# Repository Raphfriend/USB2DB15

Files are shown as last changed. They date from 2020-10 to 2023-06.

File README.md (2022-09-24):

# USB2DB15 - Supergun Adapter  


A simple Atmega328P based USB to DB15 adapter designed for use with a Supergun or Neo-Geo system.

<p align="center">
  
 <br>
  <b>USB2DB15 with a Sega Astro City Mini Arcade Stick</b><br>
<br>
	</p>  	

### 1. Features:

- USB input to support most modern HID compatible controllers
- 1ms polling, meaning a low latency and fast response from the USB2DB15
- Open Source firmware, so everyone on the community can collaborate
- DB15 pinout standard, ready for Neo Geo, Minigun, and HAS Superguns
- 4 customizable and storable mapping configurations
- 10 customizable and storable controller profiles
- Status LED
- Protection circuit for your beloved controllers

### 2. Technical information:

The USB2DB15 adapter is an Open Sourced device based on an AVR microcontroller. It adapts a USB controller for use with a Jamma PCB via a Supergun or Neo-Geo hardware with controller ports. Presently, a variety of common controllers are supported; such as ones that follow the PS3/PS4 DualShock, PS5 DualSense and Xbox 360/One protocols. Due to the diversity of controllers available and differing standards there may be some controllers that will not work with the USB2DB15 or may not work as intended. Please be patient during these early stages. Feel free to contact the developers with additional information and requests for help with your USB2DB15 adapter via our communication channels (GitHub, Discord, Arcade-Projects forum).

We are using a modified USB Host Shield 2.0 library for controller IDs that aren't natively supported.

In regards to hardware there are currently two options:

- A Custom PCB that accommodates and integrates an Arduino Pro Mini, USB Shield Mini and other relevant hardware.
- USB2DB15 2.0 Ver, a pre-built, single PCB that incorporates all the required hardware in a standalone form.
- USB2DB15 CS Ver, same as 2.0 Ver, but with a focus on PCB consolization. In place of the DB15 controller connector, this board has screw terminals and a 20 pin header which is compatible with a 20-pin Brook Fighting Board Cable.

Alternatively you can simply use a breadboard to connect it all together. 

If you are building the open source version for yourself, a basic understanding of Arduino and its programming environment is required. Visit [arduino.cc](https://arduino.cc) to help you get started.

<p align="center">
  
 <br>
  <b>USB2DB15 pinout standard</b><br>
<br>

### 3. Open Source Required Hardware:

* The USB2DB15 uses an Atmega328P AVR. Any Arduino that utilizes this microcontroller such as the Mini Pro, Nano, and Uno are suitable. The Custom PCB accommodates an Arduino Mini Pro and USB Host Shield Mini.
* USB Host Shield Mini if using an Arduino Pro Mini / Nano. Full sized USB Host Shield for Uno.
* An FTDI programmer is required for the Arduino Pro Mini. This is not required if using an Arduino Nano or Uno.
* USB2DB15 Custom PCB or a breadboard to complete all the connections between the AVR and USB Host Shield.
* DB15 female connector.

<p align="center">
  
 <br>
  <b>Arduino Pro Mini and Usb Host Shield Mini</b><br>
<br>
	</p>  	

If utilizing the Custom PCB in conjunction with an Arduino Pro Mini and Mini USB Shield, a BOM is available from the repositories section within the PCB folder. 

##### Jumper settings:

- SJ1: Bridge this jumper ONLY to disable 5V protection.
- SJ2: Bridge this jumper ONLY to enable 5V protection.
- JP2: 5V solder point (see information below regarding USB VBUS).

Due to variances of Mini Pro PCB's, A4 and A5 may be in different locations. Please pay attention to this.

<p align="center">

 <br>
  <b>Custom PCB 1.2 for Arduino Pro Mini</b><br>
</p>

### 4. Installation:

Download the  <a href="https://github.com/Raphfriend/USB_Host_Shield_2.0">USB Host Shield 2.0 library</a>  and install it to the Arduino IDE. Open the INO file (RFUSB_to_DB15.ino) and program it to your AVR.  

If you have a USB Host Shield Mini, you will need to CUT the trace after the 2K2 resistor near the USB VBUS pin. Solder a wire from JP2 of the CUSTOM PCB to the through-hole VIA labeled '5V' as depicted in the picture below.

<p align="center">
  
</p>

This enables devices that require +5V power to function correctly, as by default the USB Host Shield Mini only supplies 3.3V to the VBUS pin of the USB connector.

The remainder is plug and play. 

If you are not using a prefabricated PCB, please view the schematic for wiring information.

#### 4.1. Arduino Pro Mini + USB Shield Mini:
[See FLASHING.md for instructions.](FLASHING.md)

#### 4.2. Arduino Uno + USB Host Shield:

1. Install Arduino IDE.
2. Mount the USB Host Shield to the Arduino Uno correctly.
3. Connect the Arduino Uno to your PC via its USB B cable. 
4. In the Arduino IDE navigate to "Tools" -> "Board" -> "Arduino AVR Boards" and select "Arduino Uno".
5. In the Arduino IDE navigate to "Tools" -> "Port" and choose the Arduino Device. 
6. In the Arduino IDE navigate to "Tools" -> "Programmer" and select "AVRISP MKII".
7. Obtain the library path (Arduino IDE -> File -> Preference-> Settings->Sketchbook location) and drop the required library "USB_Host_Shield_20" to the library directory.
8. Obtain the INO firmware (RFUSB_to_DB15.ino).
9. Open the INO file with the Arduino IDE (with the Arduino Uno connected to your PC) and select Sketch -> Upload.
10. Wait for the sketch to be uploaded as indicated in the console window at the bottom of the Arduino IDE software.

### 5. Supported Controllers:

[See Compatibility.md for a detailed list of supported controllers.](COMPATIBILITY.md)

### 6. Software Usage
#### 6.1 Controller Profiles
The Adapter can store profiles for up to 10 unique controller models*. Controllers of the same make and model will share the profiles.
Each controller has 4 profiles associated with it. Should you plug in an 11th controller the system will replace the oldest controller you have set up.
Next oldest for the 12th and so on. This may cause you to have to set up older controllers again if you resume using them.

These can be accessed by pressing SELECT(COIN) + one of the four directions.
Thus if you wanted the first profile you would press SELECT + UP, the Second SELECT + RIGHT, and so on.
The adapter will remember what profile you were using and automatically switch to it when you use the controller again.

To change the key bindings of a profile. First change to the profile you want to setup.
While holding SELECT for at least 3 seconds, press buttons 1 - 6 in order. Then release SELECT to lock in the binding.
Finally release SELECT to lock in the binding.

*XBox One controllers appear to the system as the same make and model and thus use the same profiles even if they are different controllers.

### Shell

[AvramCE](https://twitter.com/avramce) has created a [3D printed case](https://www.thingiverse.com/thing:5170415) that you can print for your USB2DB15.

### How it looks in real life?

When you put all the parts together, USB2DB15 should look like this.
<p align="center">
  
	 <br>
  <b>Setup and photo by <a href="https://twitter.com/Focux11">@Focux</a> </b>
	</p>  	
<p align="center">
  
	 <br>
    <b>Setup and photo by <a href="https://twitter.com/_atrac17">@_atrac17</a> </b>
	</p>  	

### Support this project

If you have found USB2DB15 useful, please consider funding it and making a donation so that we may continue our work by obtaining additional controllers, equipment, and everything else required to keep this project alive and growing.



### Is this product available to buy? YES!

We sell the USB2DB15 directly. You will receive a premium edition that is slightly different from the open-source version but has the same features.
You can choose from a variety of shell color options, and you will get detailed instructions following your purchase.
There are two versions: the standard DB15 and the CS Ver., which is targeted towards Jamma PCB consolizations. 

<a href="https://ko-fi.com/s/b6c3d01043">Access our shop by clicking here or on the images below. </a>

<p align="center">
<a href="https://ko-fi.com/s/b6c3d01043">
  
</p>

<p align="center">
<a href="https://ko-fi.com/s/b6c3d01043">
  
</p>

<p align="center">
<a href="https://ko-fi.com/s/b6c3d01043">
  
</p>

<p align="center">
<a href="https://ko-fi.com/s/b6c3d01043">
  
</p>

### Where can I get more help, if I need it?

Via Arcade-Projects forum or RF Projects Discord server.

<p align="center">
<a href="https://www.arcade-projects.com/forums/index.php?thread/14205-open-source-usb-to-db15-for-supergun-adapter/">
  
</p>

<p align="center">
<a href="https://discord.gg/XKCjtpH">
  
</p>

### LEGAL

USB2DB15 or any of its maintainers are in no way associated with or endorsed by Nintendo, Sony, SNK, Microsoft, 8BitDo, Sega, Brook, Mad Catz, Nacon, Honcam, DaemonBite, Buffalo, Qanba, Razer, Retrobit, Toodles, Hori or any other company not implicitly indicated. All other brands or product names are the property of their respective holders.

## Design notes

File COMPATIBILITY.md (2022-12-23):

## Known Compatible Controllers by Manufacturer
This is a list of tested controllers. Please reach out to our Discord server if you have a controller not listed here and wish to be a tester.  You will need to test each beta version of the software for regressions

### 8BitDo
- M30 Bluetooth Controller
	- Via wired connection
	- Place controller into D-INPUT mode by holding B + START upon powering ON controller
	- Press SELECT + DPAD UP to enable digital DPAD
- SFC30 (Via wired connection)
- NES & SNES Bluetooth Receivers (Firmware v1.33) 
  - NES & SNES Bluetooth receviers tested compatible with the following controllers:
    - Sony PS4 DS4
    - Nintendo Switch Pro controller
    - 8BitDo Arcade Stick (November 2020 version) on Switch mode and Firmware 1.03
    - 8BitDo SFC30
    - 8BitDo M30 Bluetooth controller (controller must be placed in either MacOS mode by holding A + START or X-Input mode by holding X + START upon powering on controller)

### Buffalo
- SNES Classic GamePad

### Brook
- Brook FIGHTING BOARD PS3/PS4
- Brook Universal Fighting PCB
- Brook Retro Board
- Brook Wingman XB Converter Wireless Adapter OG and 2

### DaemonBite Retro Controllers To USB Adapters:
- NES/SNES (VID/PID 2341:8037)
- SEGA Saturn (VID/PID 2341:8030)
- SEGA MegaDrive/Genesis (VID/PID 2341:8031)

	DaemonBite Retro Controllers To USB Adapters project uses an Arduino Pro Micro, when the code is burned, will show as Leonardo and a VID/PID will be attached. Each controller code own especific output patterns and can't use same ID Hardwares on the USB2DB15 adapter, so we choose to change the PID on Saturn and on (NES/SNES is standard) to make the code working well. It won't change anything on the right functionalities for both adapters in any device (Windows PC or MiSTer, for example).
	
	- To do that, just find Arduino > avr > boards.txt file; 
	- Save this file in a another place so you don't lose it. 
	- Find something like it: 
		micro.build.vid=0x2341
		micro.build.pid=0x8037
		micro.build.usb_product="Arduino Micro"

	- Change for something like it:

			micro.build.vid=0x2341		
			micro.build.pid=0x8030 (PID used for Saturn)
			micro.build.usb_product="Arduino Micro"
	- Save the file.

### Feir
- Feir Wired FR-225C Controller for PlayStation 4

### FeralAI
- Pico Fighting Board GP2040 (PS3/DirectInput Mode)

### Generic
- Generic SNES USB pad
- Generic Zero Delay Controller

### Honcam
- HC-J2003

### HORI
- HORIPAD 3 Mini
- Hori Fighting Edge PS4 (requires USB HOST SHIELD 2.0 update)
- HORI Wireless Controller Lite
- Fighting Stick 3
- Fighting Stick V3
- Fighting Commander (PS3 mode)
- Fighting Stick Mini 4 (requires USB HOST SHIELD 2.0 update)
- Real Arcade Pro.3 SA (PS3 mode)
- Real Arcade Pro.3 Premium VLX (PS3 mode)
- Real Arcade Pro V HAYABUSA (PS3 and PS4 modes)
- Real Arcade Pro - Soul Calibur VI Edition for Xbox One (requires USB HOST SHIELD 2.0 update)

### Logitech
- F310 

### Mad Catz
- Street Fighter IV - Arcade FightStick Tournament Edition PS3 (Round 1 & Round 2 versions)
- Street Fighter V FightStick Alpha (PS3 and PS4 Modes)
- Street Fighter V Arcade FightStick TE2+ (PS4 Mode)
- Street Fighter V Arcade FightStick TES+ (PS4 Mode)

### Microsoft
- Xbox One Controller
- Xbox Series S|X Controller

### Nacon
- Daija (PS3 and PS4 Modes)

### PowerA
 - FUSION Wired FightPad Gaming Controller for PlayStation 4

### PXN 
 - PXN 0082 Arcade Stick

### Qanba
- Crystal (PS3 and PS4 Modes)
- Drone (PS4)
- Obsidian (PS3 and PS4 Modes)

### Razer
- Panthera
- Panthera EVO
- Raiju Ultimate 

### Retrobit
- Sega Saturn Wireless Controller 2.4GHz (Via wireless USB receiver)
	- Press START + UP to enable digital DPAD
### SEGA
- Astro City Mini Arcade Stick
- Astro City Mini Control Pad

### SNK
- Neo Geo Mini Pad

### Sony
- Dual Shock 3
- PS4 Offical Controllers
- PS4 Wireless Adapter
- PS5 DualSense
- PlayStation Classic Controller

### Toodles
- MC Cthulhu

### Universal PCB Project
- Universal PCB Firmware 29

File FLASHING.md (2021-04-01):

# How to Flash the USB2DB15

## 1. Prerequisites

### Required hardware:
* USB FTDI Programmer
* USB2DB15 with header pins on the FTDI programming interface

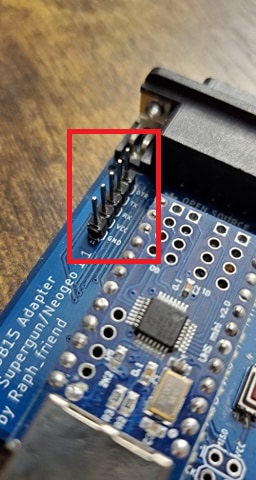
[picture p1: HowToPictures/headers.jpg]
Headers


### Required software:
* [Arduino IDE](https://www.arduino.cc/en/software)

* This modified USB Host Shield must be placed in your Arduino Libraries Folder.
[Modified USB Host Shield 2.0](https://github.com/Raphfriend/USB_Host_Shield_2.0)

Arduino Libraries Folder

---
## 2. Download the USB2DB15 Project

### Option 1 : Download as ZIP

Download and extract the [USB2DB15 Project](https://github.com/Raphfriend/USB2DB15/archive/refs/heads/master.zip).<br>
Open RFUSB_to_DB15.ino in your Arduino IDE.

### Option 2 : Download as Git repo

Install the [Git Command Line Interface](https://git-scm.com/downloads)

Open your favorite terminal and use git to clone the USB2DB15 project.

```
    git clone https://github.com/Raphfriend/USB_Host_Shield_2.0.git
```

Navigate into the USB2DB15 project and ensure you have the latest changes.

```
    cd .\USB2DB15\
    git fetch -a
    git reset --hard origin/master
```

Open RFUSB_to_DB15.ino in your Arduino IDE.

---
## 3. Connecting the FTDI Programmer

1. Connect the programmer to the USB2DB15 as illustrated. Remember, TX (Transmit) from one device connects to RX (Receive) on the other.

| USB FTDI Programmer | USB2DB15 |
| --- | --- |
| VCC | VCC |
| GND | GND |
| TXD | RX |
| RXD | TX |
| RTS/DTR | DTR |
| CTS | Unused |

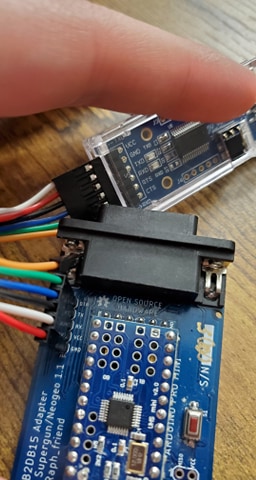
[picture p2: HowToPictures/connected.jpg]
Connected USB2DB15


2. If your programmer has a jumper for using 5V or 3.3V, set it to 5V. The USB2DB15 will be powered by the programmer while flashing the software. Plug in the USB programmer.

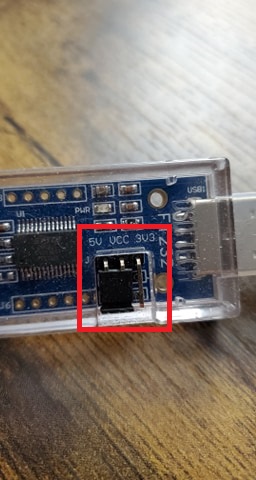
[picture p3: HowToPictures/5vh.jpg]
5Vh


3. In the Arduino Software, set the flashing mode to 5V as well.

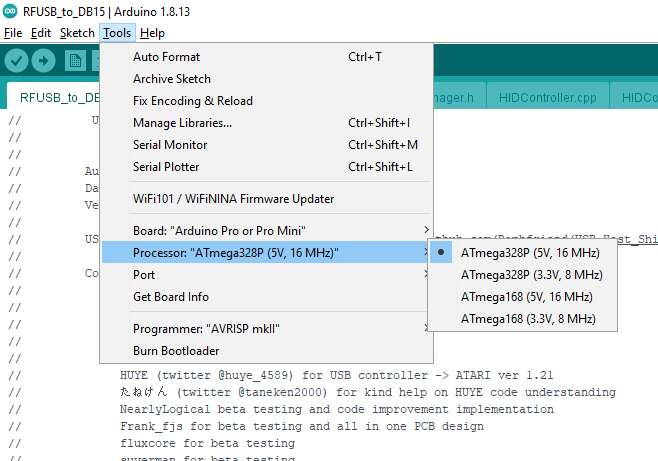
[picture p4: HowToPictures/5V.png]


4. Set the appropriate COM Port for your FTDI Programmer. This should be recognized by the Arduino IDE.

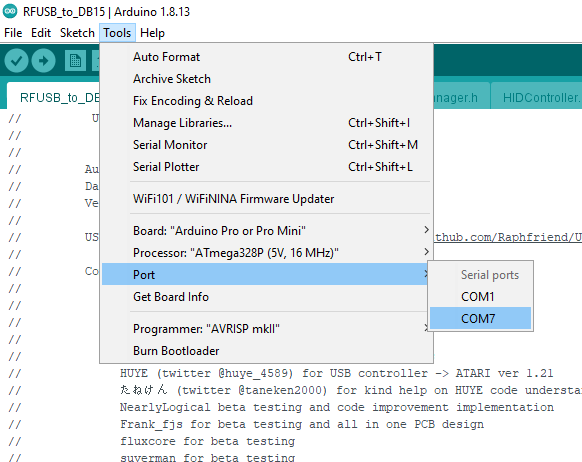
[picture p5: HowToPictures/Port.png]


5. Upload the software to the USB2DB15 by selecting Sketch->Upload. Do not use <del>Upload Using Programmer</del>

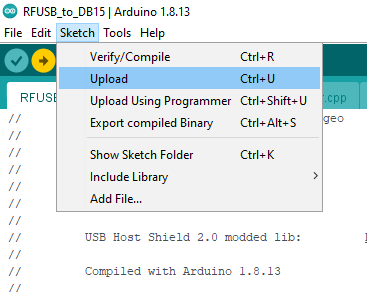
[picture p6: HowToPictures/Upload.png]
Upload


---
## Success!!

Your USB2DB15 should now be updated with the latest software. Feel free to disconnect everything once the upload process has finished and enjoy your games!

---
## FAQ/Troubleshooting

If you run into any issues, please join us on our [Discord Channel](https://discord.gg/XKCjtpH).

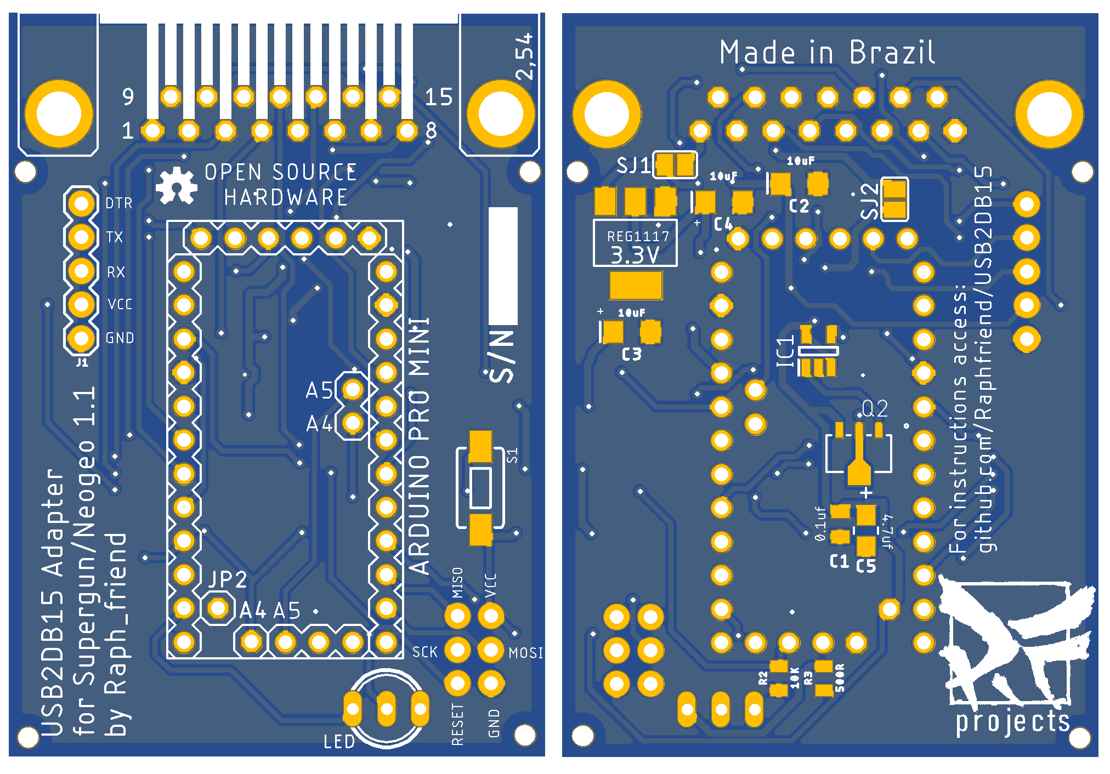
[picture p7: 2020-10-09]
RFUSBtoDB15Adapter.png

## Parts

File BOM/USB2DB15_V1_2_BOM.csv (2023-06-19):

Designator | Component | Footprint | LCSC Part #
3.3V | REG1117 | SOT223
IC1 | S-816A40AMC-BAPT2U | SOT95P275X130-5N
Q2 | 2SA1213-Y(TE12L F) | PW-MINI_TOS
C1 | 0.1uf | 0805 SMD Ceramic
C2, C3 and C4 are optional | 10uF | EIA3216
C5 | 4.7uf | CAPMP3.4X1.6_1.8N_KEM
R2 | 10K | 0805 SMD
R3 | 33R-500R | 0805 SMD
S1 | TACTILE-SWITCH | 3x6x2.5mm SMD
ARDUINO | Arduino Pro Mini 5 or 3V

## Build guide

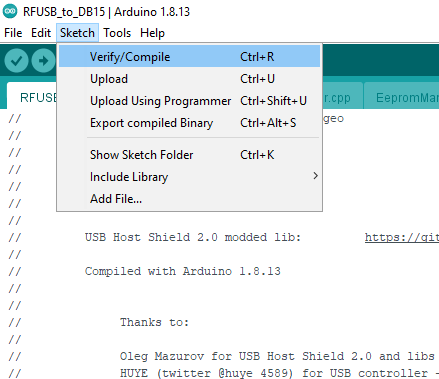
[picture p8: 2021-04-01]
HowToPictures/Compile.png

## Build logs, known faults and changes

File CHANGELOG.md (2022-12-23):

## [0.14.16] - 2022-12-23

### Changed
- DaemonBite SNES to USB Adapters: Changed D-Pad working comeback and exchanged button L/R layoyut. [@babapus](https://github.com/babapus)
- PID separation for SEGATOYS devices (ACS-1002, ACS-1003). [@babapus](https://github.com/babapus)

### Added

- Added Support for Astro City Mini Control Pad (ACS-1002) [@babapus](https://github.com/babapus)
- Added Support for Brook Wingman XB Converter Wireless Adapter OG and 2
- Added Support for DaemonBite SEGA MEGA DRIVE/GENESIS to USB Adapters
	Check the COMPATIBILITY.md for more instructions.

- Added Support for the Fire NEOGEO X Arcade Stick [@babapus](https://github.com/babapus)
- Added Support for Qanba Drone PS4 [@thespoonydragoony](https://github.com/thespoonydragoony)

- Added Support for XBOX SERIES S|X
	- Library updated: https://github.com/Raphfriend/USB_Host_Shield_2.0
	- USB Host Shield 2.0 files updated:
		- XBOXONE.h

## [0.14.15] - 2022-05-26

### Changed
- Fixed an issue with button mapping surrounding Mad Catz Street Fighter V Arcade FightStick TE2+ (PS4 Mode) controller.

### Added
- Added Support for Logitech F310
	- Library updated: https://github.com/Raphfriend/USB_Host_Shield_2.0
	- USB Host Shield 2.0 files updated:
		- hidescriptorparser.cpp
		- hidescriptorparser.h
		- Usb.cpp

- Added Support for Feir Wired FR-225C Controller for PlayStation 4

## [0.14.14] - 2022-05-14
### Added
- Added Support for PowerA FUSION Wired FightPad Gaming Controller for PlayStation 4
- Added Support for FeralAI Pico Fighting Board GP2040 (PS3/DirectInput Mode) 

## [0.14.13] - 2022-01-12
### Added
- Added Support for Generic Zero Delay Controller
- New PCB and Schematics for Version 1.2 added with some fixes. 

## [0.14.12] - 2021-09-09

### Added

- Added Support for Mad Catz Street Fighter V FightStick Alpha

## [0.14.11] - 2021-09-09

### Added

- Added Support for the Mad Catz Street Fighter V Arcade FightStick TE2+ (PS4 Mode)
- Added Support for the Mad Catz Street Fighter V Arcade FightStick TES+ (PS4 Mode)
- Added Support for Razer Raiju Ultimate 
- Added Support for Sony PlayStation Classic Controller

## [0.14.10] - 2021-03-31

### Added
- Added Support for the Hori Fighting Edge PS4
- Added Support for the PXN 0082 Arcade Stick
	- Library updated: https://github.com/Raphfriend/USB_Host_Shield_2.0
	- USB Host Shield 2.0 files updated:
		- PS3USB.h
		- XBOXUSB.cpp 
		- XBOXUSB.h

## [0.14.9] - 2021-03-14
### Added
- Added Support for Brook FIGHTING BOARD PS3/PS4

## [0.14.8] - 2021-02-25
### Added
- Added Support for Sony Playstation 5 DualSense

## [0.14.7] - 2021-01-21
### Added
- Added Support for the Neo Geo Mini Pad.
- Added Support for Razer Panthera EVO (PS4).

## [0.14.6] - 2020-12-19
### Added
- Added Support for the Astro City Mini Arcade Stick.
	
## [0.14.5] - 2020-11-18
### Added
- Added Support for the DaemonBite Retro Controllers To USB Adapters:
	- NES/SNES
	- SEGA Saturn
	
	Check the COMPATIBILITY.md for more instructions.

## [0.14.4] - 2020-10-12
### Changed
- Exiting bind mode after binding at least one button will clear the binds for any buttons that weren't bound
    - If you do not bind any keys, the old profile will be used instead

## [0.14.3] - 2020-10-12
### Added
- Added Support for the Qanba Crystal in both PS3 and PS4 modes (PS3 mode requires USB HOST SHIELD 2.0 update).
	- Library updated: https://github.com/Raphfriend/USB_Host_Shield_2.0
	- USB Host Shield 2.0 files updated:
		- PS3USB.cpp
		- PS3USB.h
		- PS3Enums.h

## [0.14.2] - 2020-10-09
### Added
- Added analog nub support for Xbox One controllers.
- Added `debug.h` to control serial output.
### Changed
- Fixed an issue with button mapping surrounding Xbox One and Xbox 360 controllers.
	- Files altered: `XboxOneController.cpp` `XboxUSBContrtoller.cpp` 
- Fixed an issue surrounding PS3 analog support.
	- File altered `PS3Controller.cpp`
- Removed the temporary `#define ENABLE_SERIAL` as it has been superseded by `debug.h` 

## PCB 1.1 

### Changed

- DB15 on schematic was right, but the footprint was inverted, forcing to solder the connector pins on the top side, it's now fixed.
- LED pin is now on D8 pin, so can reflec the code. 
- We are now using a 3 pin DUO COLOR LED (center cathode) for a adicitional USB status, 
so if there's any USB controller inserted and working, one LED color will be on, else, off. 
- Reset eeprom memory circuit inserted
- PCB was downsized

## [0.14.1] - 2020-10-05
### Added
- Added analog nub support for PS3 and Xbox 360 controllers.
- Added a temporary `#define ENABLE_SERIAL` to `HIDController.cpp` to free up some memory.
- Added support for HORI Real Arcad Pro - Soul Calibur VI Edition - Xbox 360 (requires USB HOST SHIELD 2.0 update).
	- Library updated: https://github.com/Raphfriend/USB_Host_Shield_2.0
	- USB Host Shield 2.0 files updated:
		- XBOXUSB.cpp
		- XBOXUSB.h 

## [0.14.0] - 2020-10-05
### Added
- Added support for Xbox 360 controllers and compatible devices. 
	- This slightly breaks custom button mapping for Xbox 360 & Xbox One controllers. I am currently diagnosing the fault and will update with a solution ASAP.
### Changed
- 8Bitdo NES/SNES wireless USB Bluetooth receviers are now handled by the XBOXUSB (360) USB Host Shield 2.0 library files.
- 8Bitdo NES/SNES wireless USB Bluetooth recevier code removed from the PS3 USB Host Shield 2.0 library files.  
	- Library updated: https://github.com/Raphfriend/USB_Host_Shield_2.0
	- USB Host Shield 2.0 files updated:
		- PS3USB.cpp
		- PS3USB.h
		- PS3Enums.h

## [0.13.7] - 2020-10-04
- Extended `Mad Catz Street Fighter IV Tournament Edition (PS3)` entry in `drivers.cpp` & `drivers.h` to support both editions (Round 1 & Round 2) of the controller.

## [0.13.6] - 2020-09-28
- Added Support for the Qanba Obsidian in both PS3 and PS4 modes

## [0.13.5] - 2020-09-18
### Added
- Added Support for 8BitDo NES & SNES Bluetooth wireless receivers (requires USB HOST SHIELD 2.0 update)
	- Sony PS4 DS4, Nintendo Switch Pro, 8BitDo M30 Bluetooth controllers tested and verified as working
	- Note: 8BitDo receivers must be on Firmware v1.33
- Added Support For Hori Fighting Stick Mini 4 (requires USB HOST SHIELD 2.0 update)
	- Library updated: https://github.com/Raphfriend/USB_Host_Shield_2.0
	- USB Host Shield 2.0 files updated:
		- PS3USB.cpp
		- PS3USB.h
		- PS3Enums.h

## [0.13.4] - 2020-09-16
### Added
- Added Support for 8BitDo SFC30
- Altered 8BitDo M30 to use D-INPUT mode

## [0.13.3] - 2020-09-16
### Added
- Added Support for Generic SNES USB pad
- Refactored the Retrobit Saturn Wireless driver

## [0.13.2] - 2020-09-15
### Added
- Added Support for Honcam HC-J2003

## [0.13.1] - 2020-09-12
### Added

- Added Support for Nacon Daija in PS3 and PS4 modes

## [0.13.0] - 2020-09-12
### Added

- Added a new LED class to control an LED connected to digital pin 8.
	- LED::On(); Turns the LED ON
	- LED::Off(): Turns the LED OFF
	- LED::Blink(n); Blinks the LED where n equals the number of desired blinks
	- The LED is set to turn ON when Bind mode is entered and remains on until Bind mode is exited, thus turning the LED OFF. 
	- The LED will blink with a profile change and blinks an amount of times that corresponds to the profile number.
- Added a resetEEPROM() function that clears all EEPROM memory, thus clearing profiles and bindings. This is controlled via a tactile switch connected to analog pin 6.

## [0.12.0] - 2020-09-11
### Changed

- Profiles are now per controller rather than shared between all controllers
- There are now only 4 profiles, they are mapped to SELECT + directional(UP, DOWN, LEFT, RIGHT)
- Adapters can remember up to 10 controllers, if more then 10 are plugged in, the oldest one will be forgotten.

## [0.11.0] - 2020-08-30
### Added

- Support for user defined profiles. In order to do this it makes the following changes.

### Changed

- Profiles are now stored in EEPROM
- A new EepromManager class is added. It initializes the EEPROM with default values and Manages Access to the EEPROM
- Added a GetButtonClick function to Controller. It returned true only once each time a button is pressed.
- Implemented GetButtonClick for the PS3, XBoxOne and HID controllers
- Pulled Normal Output into it's own function
- Added BindMode in addition to NormalMode to handle when the adapter is binding to profiles

## [0.10.0] - 2020-08-23
### Added
- Refactored the way button input was processed to allow for profiles
- Added profile support to PS3, Xbox and HID controllers
- Controller drivers were rewritten currently the following controllers are supported as HID devices:
  - 8BitDo M30 wired Controller
  - iBUFFALO Snes Classic Controller
  - Brook Universal Fighting PCB
  - HORI Fighting Commander
  - HORIPAD in ps4 mode
  - HORI Wired Controller lite
  - HORI Real Arcade Pro.3 PS3 mode
  - HORI Real Arcade Premium VLX
  - HORI Real Arcade Pro V HAYABUSA PS3 and PS4 Modes
  - Razer Panthera
  - Retrobit Sega Saturn Wireless
  - Sony PS4 and PS3 Controllers
  - Sony Wireless Adapter
  - Universal PCB firmware version 29
  - Xbox One official and some 3rd Party controllers
  - 4 Builtin Profiles.  They can be switch by holding UP + SELECT + BUTTON 1-4 (button number is relative to the default profile)
  - Button 1: Default profile
  - Button 2: Default but the rows are swapped
  - Button 3: SNES style where button 6 is on L1
  - Button 4: SNES with rows swapped

## [0.9.1] - 2020-08-21
### Added

- Added support for HORI Real Arcad Pro - Soul Calibur VI Edition - Xbox One (requires USB HOST SHIELD 2.0 update) [@kitsune](https://github.com/kitsune)
	- Library updated: https://github.com/Raphfriend/USB_Host_Shield_2.0
	- USB Host Shield 2.0 files updated:
		- XBOXONE.h

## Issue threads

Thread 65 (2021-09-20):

in the file USB2DB15.h Controller.h is in lower case

bbarthes, 2021-09-20:
Hello,

In the file USB2DB15.h line 9, Controller.h is in lower case.
This causes a compilation error on the case-sensitive system (linux).

Raphfriend, 2021-09-23:
When you set the "C" it compile all right?

bbarthes, 2021-09-23:
Yes

Raphfriend, 2022-05-15:
Fixed on [PR 69](https://github.com/Raphfriend/USB2DB15/pull/69)

Closed 2022-05-15.

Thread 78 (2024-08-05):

Capacitors and LED

sageofeon, 2024-08-05:
Can I use ordinary ceramic SMD capacitors? And which LED with a common anode or cathode?

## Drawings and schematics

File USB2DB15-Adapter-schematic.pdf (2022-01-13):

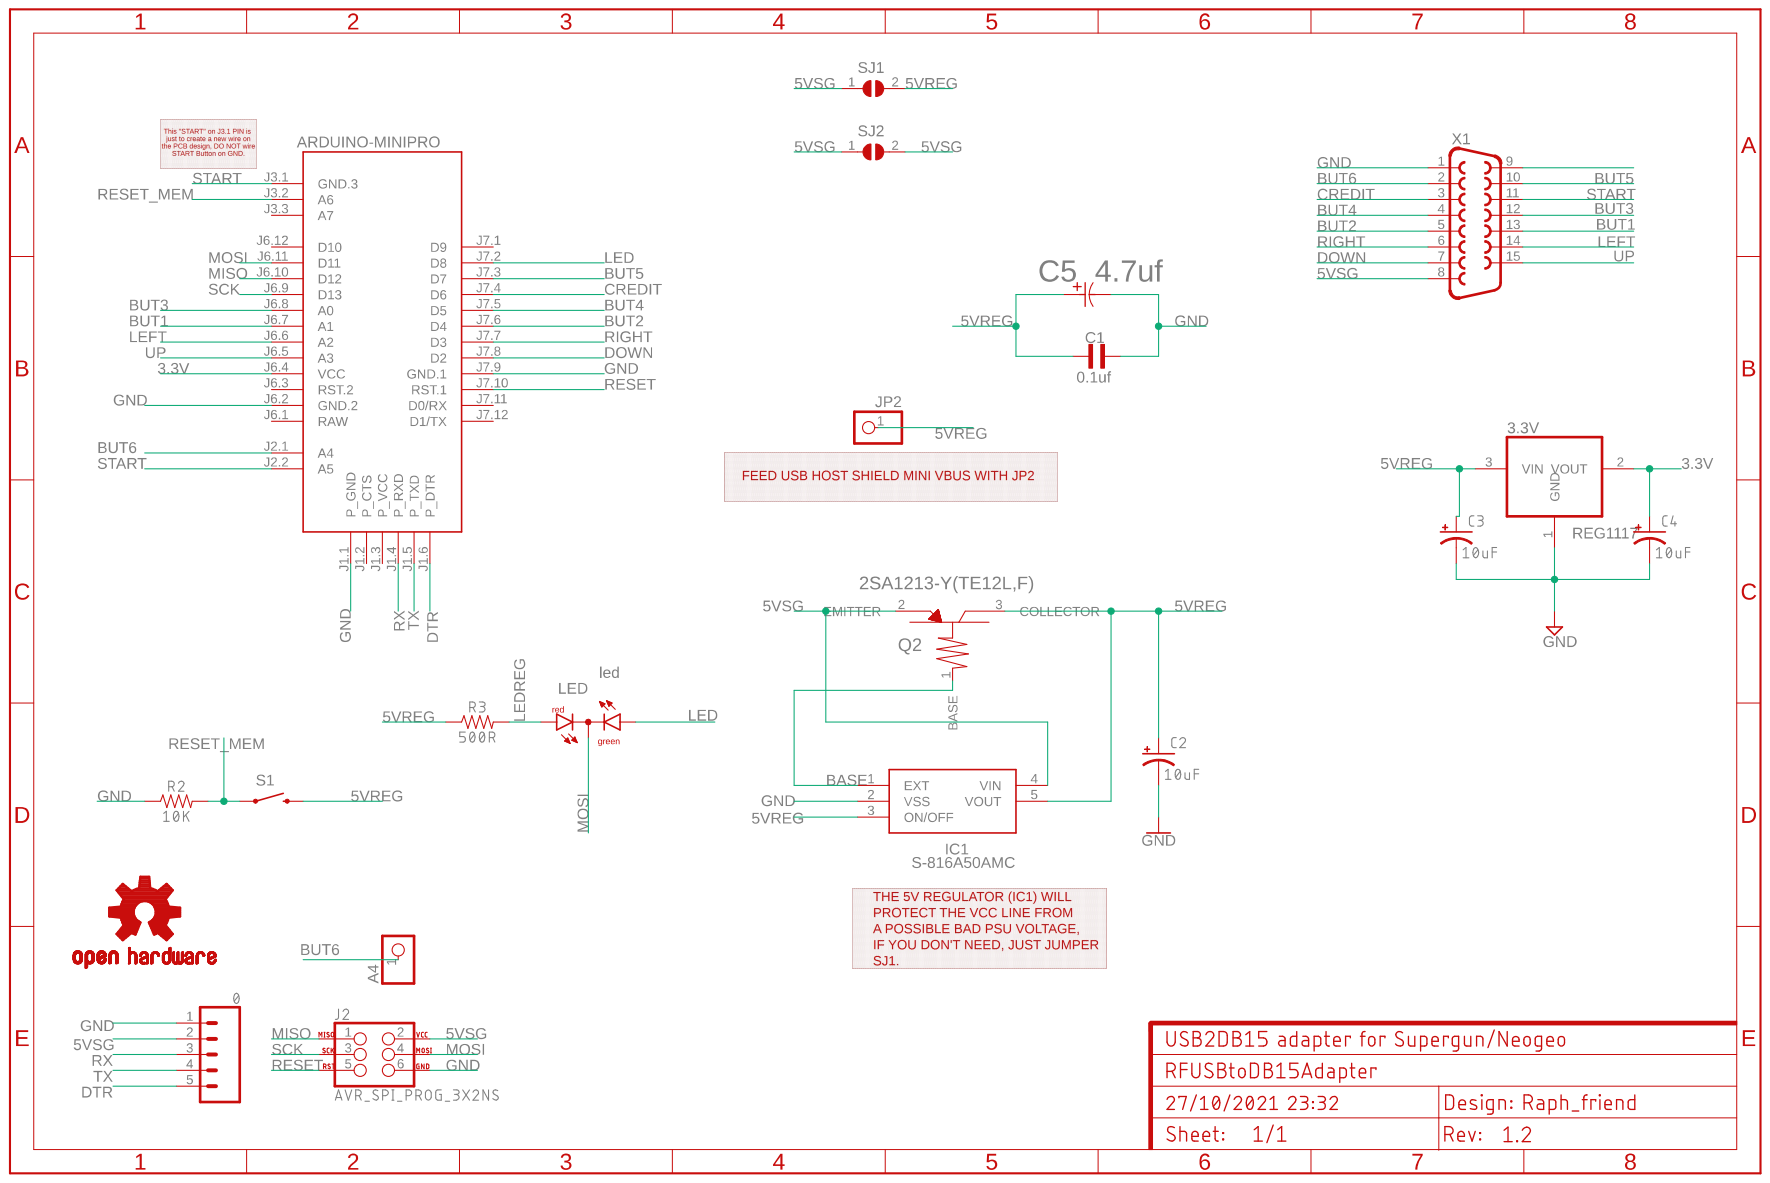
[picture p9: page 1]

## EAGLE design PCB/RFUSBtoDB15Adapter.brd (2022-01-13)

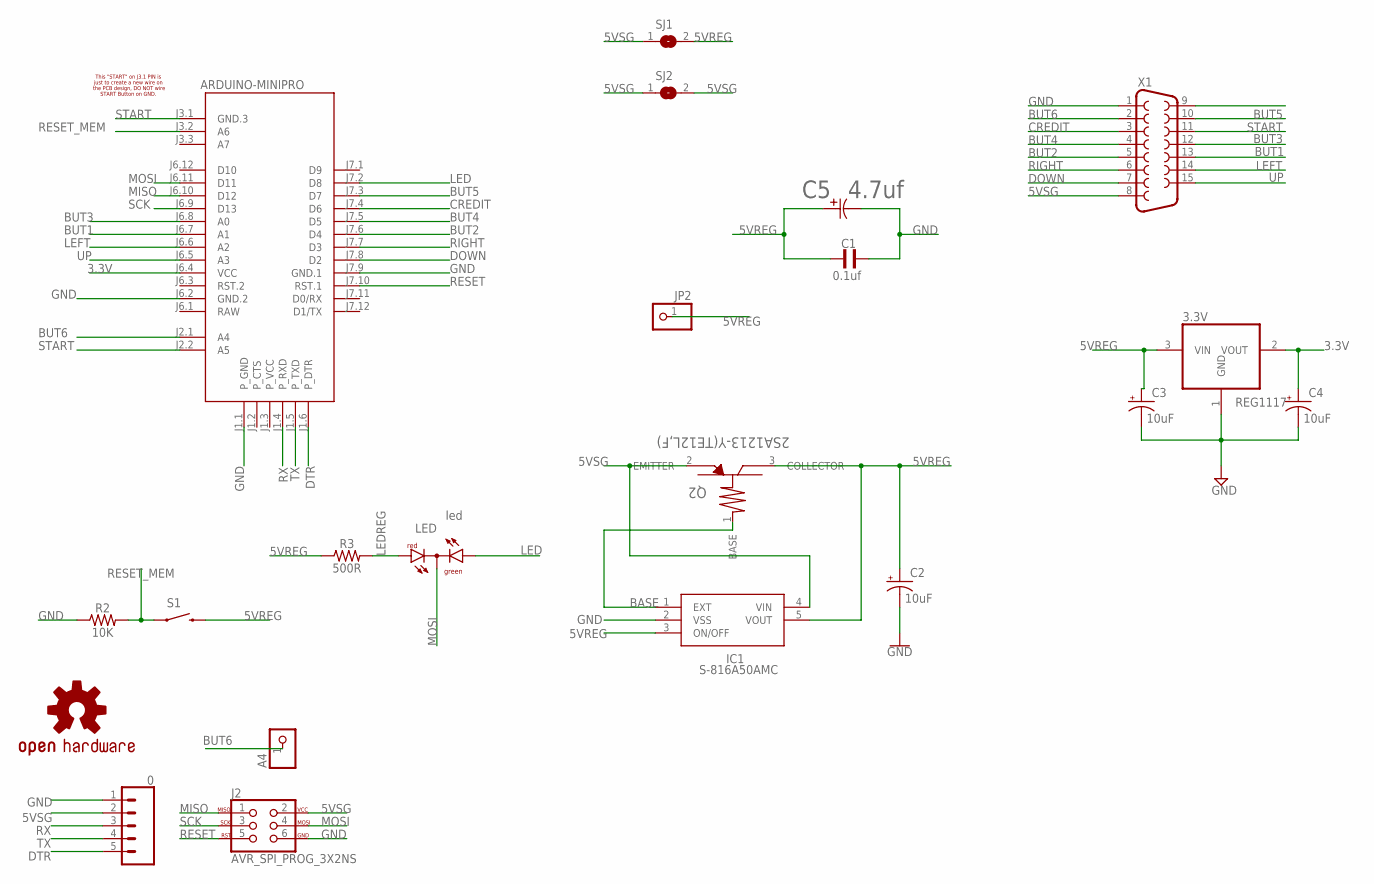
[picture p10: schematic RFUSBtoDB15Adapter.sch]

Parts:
3.3V: REG1117; SOT223
A4: 0; 1X01
ARDUINO-MINIPRO: ARDUINO-PRO-MINI-5.0V; ARDUINO-PRO-MINI
C1: 0.1uf; WCAP-CSGP_0805_REFLOW
C2, C3, C4: 10uF; EIA3216
C5: 4.7uf; CAPMP3.4X1.6_1.8N_KEM
IC1: S-816A40AMC-BAPT2U; SOT95P275X130-5N; MANUFACTURER_PART_NUMBER S-816A50AMC
J1: 0; 1X05
J2: AVR_SPI_PROG_3X2NS; 2X3-NS
JP2: JP2; 1X01
LED: led; DUOLED-C-5MM
LOGO1: OSHW-LOGOS; OSHW-LOGO-S
Q2: 2SA1213-Y(TE12L,F); PW-MINI_TOS
R2: 10K; 0805
R3: 500R; 0805
S1: RS032G05A3SM-SPST-MOMENTARY-SWSMD-1101NE; TACTILE-SWITCH-1101NE
SJ1, SJ2: SJ
X1: F15HP

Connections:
3.3V: 3.3V.2 (VOUT), ARDUINO-MINIPRO.J6.4 (VCC), C4.+
5VREG: 3.3V.3 (VIN), C1.2, C2.+, C3.+, C5.1, IC1.3 (ON/OFF), IC1.5 (VOUT), JP2.1, Q2.3 (COLLECTOR), R3.1, S1.2, SJ1.2
5VSG: IC1.4 (VIN), J1.2, J2.2, Q2.2 (EMITTER), SJ1.1, SJ2.1, SJ2.2, X1.8
BASE: IC1.1 (EXT), Q2.1 (BASE)
BUT1: ARDUINO-MINIPRO.J6.7 (A1), X1.13
BUT2: ARDUINO-MINIPRO.J7.6 (D4), X1.5
BUT3: ARDUINO-MINIPRO.J6.8 (A0), X1.12
BUT4: ARDUINO-MINIPRO.J7.5 (D5), X1.4
BUT5: ARDUINO-MINIPRO.J7.3 (D7), X1.10
BUT6: A4.1, ARDUINO-MINIPRO.J2.1 (A4), X1.2
CREDIT: ARDUINO-MINIPRO.J7.4 (D6), X1.3
DOWN: ARDUINO-MINIPRO.J7.8 (D2), X1.7
DTR: ARDUINO-MINIPRO.J1.6 (P_DTR), J1.5
GND: 3.3V.1 (GND), ARDUINO-MINIPRO.J1.1 (P_GND), ARDUINO-MINIPRO.J6.2 (GND.2), ARDUINO-MINIPRO.J7.9 (GND.1), C1.1, C2.-, C3.-, C4.-, C5.2, IC1.2 (VSS), J1.1, J2.6, R2.1, X1.1
LED: ARDUINO-MINIPRO.J7.2 (D8), LED.AX (AG)
LEDREG: LED.AR, R3.2
LEFT: ARDUINO-MINIPRO.J6.6 (A2), X1.14
MISO: ARDUINO-MINIPRO.J6.10 (D12), J2.1
MOSI: ARDUINO-MINIPRO.J6.11 (D11), J2.4, LED.C
RAW: ARDUINO-MINIPRO.J6.1 (RAW)
RESET: ARDUINO-MINIPRO.J7.10 (RST.1), J2.5
RESET_MEM: ARDUINO-MINIPRO.J3.2 (A6), R2.2, S1.1
RIGHT: ARDUINO-MINIPRO.J7.7 (D3), X1.6
RX: ARDUINO-MINIPRO.J1.4 (P_RXD), J1.3
SCK: ARDUINO-MINIPRO.J6.9 (D13), J2.3
START: ARDUINO-MINIPRO.J2.2 (A5), ARDUINO-MINIPRO.J3.1 (GND.3), X1.11
TX: ARDUINO-MINIPRO.J1.5 (P_TXD), J1.4
UP: ARDUINO-MINIPRO.J6.5 (A3), X1.15

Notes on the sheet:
This "START" on J3.1 PIN is just to create a new wire on the PCB design, DO NOT wire START Button on GND.

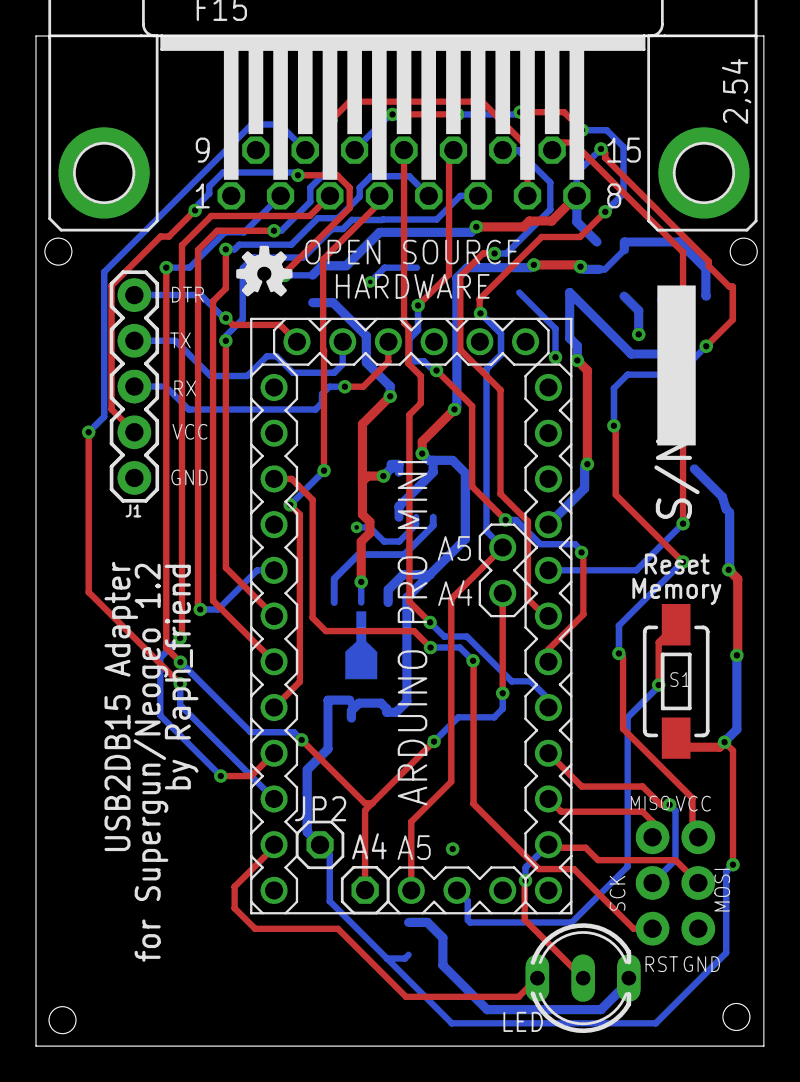
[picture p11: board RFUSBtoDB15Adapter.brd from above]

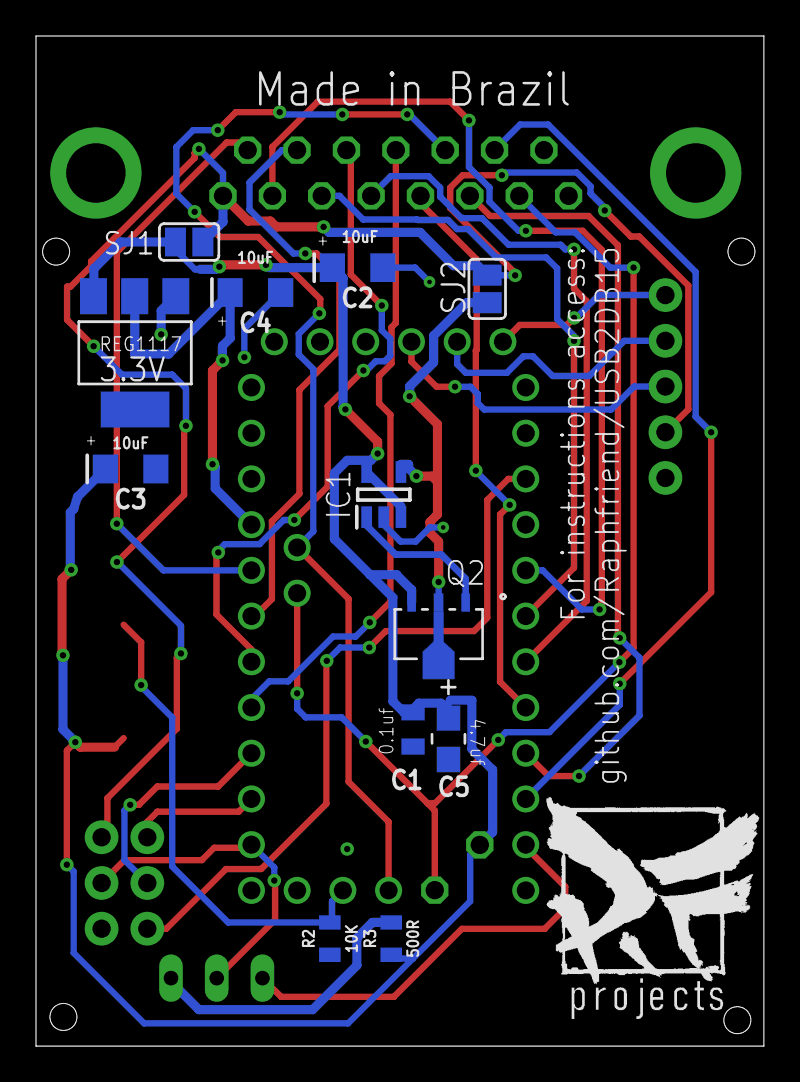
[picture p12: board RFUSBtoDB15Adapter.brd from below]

Board: 2 copper layers, 40.4 x 56.1 mm, 22 parts (13 on the bottom side), 27 nets.

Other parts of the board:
U$2: RF_LOGO

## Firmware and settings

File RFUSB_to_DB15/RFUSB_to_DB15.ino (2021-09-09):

//          USB2DB15 adapter for Supergun/Neogeo
//
//
//         Author:           Raph_friend
//         Date:             06.07.2020
//         Version:          0.14.8
//
//         USB Host Shield 2.0 modded lib:         https://github.com/Raphfriend/USB_Host_Shield_2.0
//
//         Compiled with Arduino 1.8.15
//
//
//              Thanks to:
//
//              Oleg Mazurov for USB Host Shield 2.0 and libs
//              HUYE (twitter @huye_4589) for USB controller -> ATARI ver 1.21
//              たねけん (twitter @taneken2000) for kind help on HUYE code understanding
//              NearlyLogical beta testing and code improvement implementation
//              Frank_fjs for beta testing and all in one PCB design
//              fluxcore for beta testing
//              suverman for beta testing
//              akiramishima for beta testing
//              SpaceJockey for beta testing
//
//
//            メインプログラム、コントローラタイプ(TYPE_PS4, TYPE_MDmini) :
//
//            コントローラタイプ(TYPE_PSC, TYPE_RAP3, TYPE_RAP4, TYPE_SNES, TYPE_RETROFREAK) :
//
//

// Override USB Polling freqency --This needs to go before includes--
#define POLLING_OVERRIDE 1000

#include <XBOXONE.h>
#include <XBOXUSB.h>
#include <PS3USB.h>
#include <EEPROM.h>
#include <usbhid.h>
#include <hiduniversal.h>

#include "EepromManager.h"
#include "HIDController.h"
#include "PS3Controller.h"
#include "XBoxOneController.h"
#include "XBoxUSBController.h"
#include "USB2DB15.h"
#include "LED.h"
#include "debug.h"

#ifdef dobogusinclude
#include <spi4teensy3.h>
#endif
#include <SPI.h>

#define ANALOG_BUTTON_PIN A6

USB Usb;
PS3USB PS3(&Usb);
XBOXONE Xbox(&Usb);
XBOXUSB Xbox360(&Usb);

EepromManager Eeprom;
HIDController HIDCon(&Usb);
PS3Controller PS3Con(&PS3);
XBoxOneController XBoxCon(&Xbox);
XBoxUSBController XBox360Con(&Xbox360);
USB2DB15 Usb2db15(PS3Con, XBoxCon, XBox360Con, HIDCon, Eeprom);

uint8_t resetLock = 0;

void setup() {
  #ifndef RELEASE_MODE
  Serial.begin(115200);

  while (!Serial);

  byte i, j;

  if (Usb.Init() == -1) {
    Serial.print(F("\r\nOSC did not start"));
    while (1);
  }
  #endif
  pinMode(LED_PIN, OUTPUT);
}

void loop() {
  LED::Update();

  if (analogRead(ANALOG_BUTTON_PIN) > 800) {
    if(!resetLock) {
      LED::Blink(3, LED::BLINK_RATE_RESET);
      #ifndef RELEASE_MODE
      Serial.println("Resetting");
      #endif
      Usb2db15.FactoryReset();
      resetLock = 1;
    }
  } else {
    resetLock = 0;
  }

  Usb.Task();

  delay(1);

  Usb2db15.GenerateOutput();

  delay(1);
}

//******************************************
// End of File
//******************************************

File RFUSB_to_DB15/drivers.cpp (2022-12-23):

//
// Created by Kitsune on 8/23/2020.
//

#include "drivers.h"
#include "debug.h"

/**
 * Looks up a controller based on VID and PID and configures a HIDController to
 * work with it.
 *
 * This function takes in a VID and PID as well as a controller to configure.
 * It will look up the exact controller and invoke the proper setup function to
 * configure it. If it cannot find the controller it defaults to using the
 * HoriRAP3 setup.
 *
 * When adding new controllers to this make sure to define the VID and PID in
 * "drivers.h". If an existing setup function works completely for the
 * controller then you should use it, but if they differ even a little bit
 * please create a new function instead of adding logic to an existing setup
 * function.
 *
 * Vendor and Product IDs are defined in drivers.h
 *
 * @param vid The Vendor ID for the controller.
 * @param pid The Product ID for the controller.
 * @param controller A pointer to the HIDController that you want to configure.
 */

void setupController(uint16_t vid, uint16_t pid, HIDController *controller) {
  switch (vid) {

    case VID_8BITDO:
      switch (pid) {
        case PID_8BITDO_M30:
          setup8BitDoM30(controller);
          break;

        case PID_8BITDO_SFC30:
          setup8BitDoSFC30(controller);
          break;
             
      }
      break;

    case VID_BUFFALO:
      if (pid == PID_BUFFALO_CLASSIC) setupBuffaloClassic(controller);
      break;

    case VID_BROOK:
      if ((pid == PID_BROOK_UNIVERSAL) || (pid == PID_BROOK_FB)) setupPS4(controller);
      if (pid == PID_FEIR_PS4) setupPS4(controller);
      break;

    case VID_FIRE:
      if (pid == PID_FIRE_NEOGEOX_AS) setupFireNEOGEOXAS(controller);
      break;

    case VID_GENERIC:
      if (pid == PID_GENERIC_SNES) setupGenericSNES(controller);
      if (pid == PID_GENERIC_ZERO_DELAY) setupGenericZeroDelay(controller);
      break;

    case VID_DAEMON:
      switch(pid) {
        case PID_DAEMON_SNES:
          setupDaemonSNES(controller);
          break;
        case PID_DAEMON_SATURN:
          setupDaemonSaturn(controller);
          break;
        case PID_DAEMON_MD:
          setupDaemonMD(controller);
          break;  
      }
      break;

    case VID_HONCAM:
      if (pid == PID_HONCAM) setupHoncam(controller);
      if (pid == PID_FUSION_PS4) setupPS4(controller);
      break;

    case VID_HORI:
      switch (pid) {
        case PID_RETROBIT_SATURN:
          setupRetrobit_Saturn(controller);
          break;
        case PID_HORI_CMDR:
          setupHoriFightingCmdr(controller);
          break;
        case PID_HORI_HORIPAD:
        case PID_HORI_LITE:
        case PID_HORI_RAP_V_PS4:
          setupPS4(controller);
          break;
        case PID_HORI_RAP_PS3:
        case PID_HORI_RAP_PREMIUM:
        case PID_HORI_RAP_V_PS3:
        case PID_HORI_FS3:
        case PID_HORI_FSV3:
        default:
          setupHoriRAP3(controller);
          break;
      }
      break;
		  
	case VID_LOGITECH:
      if (pid == PID_LOGITECH) setupLogitech(controller);
      break;

    case VID_MADCATZ:
      switch (pid) {
        case PID_MADCATZ_FSA_PS4:
        case PID_MADCATZ_TESP_PS4:
          setupPS4(controller);
          break;
        case PID_MADCATZ_TE2P_PS4:
          setupMadCatzTE2Plus(controller);
          break;
        case PID_MADCATZ_FSA_PS3:
        case PID_MADCATZ_SF_PS3_RND1:
        case PID_MADCATZ_SF_PS3_RND2:
        default:
          setupHoriRAP3(controller);
          break;
      }
      break;

    case VID_NACON:
      switch (pid) {
        case PID_NACON_DAIJA_PS4:
          setupPS4(controller);
          break;
        case PID_NACON_DAIJA_PS3:
        default:
          setupHoriRAP3(controller);
      }
      break;

    case VID_QANBA:
      switch (pid) {
        case PID_QANBA_CRYSTAL_PS4:
        case PID_QANBA_DRONE_PS4:
        case PID_QANBA_OBSIDIAN_PS4:
          setupPS4(controller);
          break;
        case PID_QANBA_OBSIDIAN_PS3:
        default:
          setupHoriRAP3(controller);
      }
      break;

    case VID_RAZER:
      switch (pid) {
        case PID_RAZER_PANTHERA:
        case PID_RAZER_PANTHERA_EVO:
          setupPS4(controller);
          break;
        case PID_RAZER_RAIJU_ULT:
          setupRJU(controller);
          break;
      }
      break;
		  
    case VID_SEGATOYS:
       switch (pid) {
        case PID_SEGA_ACS_1002:
        case PID_SEGA_ACS_1003:
          setupSegaAstroCityMini(controller);
          break;
      }

    case VID_SONY:
      switch (pid) { 
		    case PID_SONY_PSC:
          setupPSC(controller);
          break;      
        case PID_SONY_PS5_NA:
          setupPS5(controller);
          break;
        case PID_SONY_PS4_JP:
        case PID_SONY_PS4_NA:
        case PID_SONY_PS4_ADAPTER:
        default:
          setupPS4(controller);
          break;
      }
      break;

    case VID_SHANWAN:
      if (pid == PID_NEOGEO_MINI_PAD) setupNeoGeoMini(controller);
      break;

    case VID_UPCB:
      if (pid == PID_UPCB) setupPS4(controller);
      break;

    default:
		  
#ifndef RELEASE_MODE
      Serial.println("Failed to find a driver for device. Using RAP PS3 as fallback");
#endif
#ifndef REDUCED_SERIAL_OUTPUT
      Serial.print("VID: ");
      Serial.print(vid, HEX);
      Serial.print(" PID ");
      Serial.println(pid, HEX);
#endif
      setupHoriRAP3(controller);
      break;
  }
}

/*
/**************************
 * Utility functions
 **************************/

/**
 * Configures a D-Pad using the lower 4 bits of the provided byte
 *
 * This function only works for DPads who are in the lower 4 bits
 * of the byte. The mask is hardcoded to 0x0F because of this
 *
 * @param index The index of the byte where the dpad is located in the USB
 *              data packet.  See HIDUniversal#ParseHIDData in the Host
 *              Shield Library for the data packet.
 * @param controller The HIDController that will be configured
 */
void generateDPad(uint8_t index, HIDController *controller) {
  controller->ConfigButton(BUTTON_UP, index, DPAD_MASK, DPAD_UP);
  controller->ConfigButton(BUTTON_UP_RIGHT, index, DPAD_MASK, DPAD_UP_RIGHT);
  controller->ConfigButton(BUTTON_RIGHT, index, DPAD_MASK, DPAD_RIGHT);
  controller->ConfigButton(BUTTON_DOWN_RIGHT, index, DPAD_MASK, DPAD_DOWN_RIGHT);
  controller->ConfigButton(BUTTON_DOWN, index, DPAD_MASK, DPAD_DOWN);
  controller->ConfigButton(BUTTON_DOWN_LEFT, index, DPAD_MASK, DPAD_DOWN_LEFT);
  controller->ConfigButton(BUTTON_LEFT, index, DPAD_MASK, DPAD_LEFT);
  controller->ConfigButton(BUTTON_UP_LEFT, index, DPAD_MASK, DPAD_UP_LEFT);
}

/**************************
 * 8BitDo GamePads
 **************************/
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

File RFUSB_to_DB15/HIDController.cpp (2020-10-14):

//
// Created by Kitsune on 8/22/2020.
//

#include "drivers.h"
#include "HIDController.h"
#include "debug.h"

/**
 * Returns if there is a controller connected and ready
 *
 * @return If there is a controller connected and ready
 */
bool HIDController::Connected() {
  isReady();
}

/**
 * Gets if the button has been clicked since the last check
 *
 * This function checks the buttonState variable to see if the bit
 * corresponding to the button is set to true. Then checks lastButtonState
 * to make sure it wasn't previously pressed.
 *
 * @param button The button to check. Defined in "device_description.h"
 * @return If the requested button is pressed
 */
bool HIDController::GetButtonClick(uint8_t button) {
  // MASK_UP is the farthest right and BUTTON_UP is zero, so shift the
  // mask button times to get the correct mask for the button
  uint32_t mask = MASK_UP >> button;

  if(button >= MAX_HID_BUTTONS) return false;

  if(clickState & mask) {
    clickState &= ~mask;
    return true;
  }
  return false;
}

/**
 * Gets the State(pressed or not) of a given button
 *
 * This function checks the buttonState variable to see if the bit
 * corresponding to the button is set to true. For directionals it checks
 * the primary direction as well as the 2 diagonals that include the direction.
 *
 * @param button The button to check. Defined in "device_description.h"
 * @return If the requested button is pressed
 */
bool HIDController::GetButtonState(uint8_t button) {
  if(button >= MAX_HID_BUTTONS) return false;

  switch (button) {
    case BUTTON_UP :
      return (buttonState & MASK_UP)  || (buttonState & MASK_UP_RIGHT) || (buttonState & MASK_UP_LEFT);
    case BUTTON_DOWN :
      return (buttonState & MASK_DOWN)  || (buttonState & MASK_DOWN_RIGHT) || (buttonState & MASK_DOWN_LEFT);
    case BUTTON_RIGHT :
      return (buttonState & MASK_RIGHT)  || (buttonState & MASK_UP_RIGHT) || (buttonState & MASK_DOWN_RIGHT);
    case BUTTON_LEFT :
      return (buttonState & MASK_LEFT)  || (buttonState & MASK_UP_LEFT) || (buttonState & MASK_DOWN_LEFT);
    case BUTTON_NULL:
      return false;
    default:
      // MASK_UP is the farthest right and BUTTON_UP is zero, so shift the
      // mask button times to get the correct mask for the button
      return (buttonState & (MASK_UP >> button));
  }
}

/**
 * Gets the Vendor ID for the controller
 * @return The Controller's Vendor ID
 */
uint16_t HIDController::GetVid() {
  return VID;
}

/**
 * Gets the Product ID for the controller
 * @return The Controller's Product ID
 */
uint16_t HIDController::GetPid() {
  return PID;
}

/**
 * Configures a button.
 *
 * This function is an alias for ConfigButton(uint8_t, uint8_t, uint8_t, uint8_t)
 * and should be used when the Mask is the same as the target value. This is often
 * true for single bit masks.
 *
 * @param button_id The button id as defined in "device_descriptor.h"
 * @param index The index in the usb packet buffer that the button is located at
 * @param mask The bit mask to target the bits that make up the button
 */
void HIDController::ConfigButton(uint8_t button_id, uint8_t index, uint8_t mask) {
  ConfigButton(button_id, index, mask, mask);
}

/**
 * Configures a Button.
 *
 * This functions configures a button for use in the ParseHIDData function.
 *
 * @param button_id The button id as defined in "device_descriptor.h"
 * @param index The index in the usb packet buffer that the button is located
 * @param mask The bit mask to target the bits that make up the button
 * @param value The value the byte should equal after the bit mask is applied
 */
void HIDController::ConfigButton(uint8_t button_id, uint8_t index, uint8_t mask, uint8_t value) {
  if (button_id >= MAX_HID_BUTTONS) return;
  #ifndef REDUCED_SERIAL_OUTPUT
  Serial.print("Button ID: ");
  Serial.print(button_id, DEC);
  Serial.print(" Index: ");
  Serial.print(index, DEC);
  Serial.print(" Mask: ");
  Serial.print(mask, BIN);
  Serial.print(" Value: ");
  Serial.println(value, DEC);
  #endif
  buttons[button_id].index = index;
  buttons[button_id].mask = mask;
  buttons[button_id].value = value;
}

/**
 * Handle any setup that needs to happen when a controller is plugged in
 *
 * This is a callback function that is invoked by the USB Shield library
 * once a controller is plugged in and successfully initalized.
 *
 * This function looks up and runs the configuration for the controller
 * that was plugged in.
 *
 * @return error number, zero for no error
 */
uint8_t HIDController::OnInitSuccessful() {
  #ifndef RELEASE_MODE
  Serial.println("Detected HID device. ");
  #endif
  ResetController();
  setupController(VID, PID, this);
  return 0;
}

/**
 * Processes in incoming USB data packet
 *
 * This is a callback function defined by HIDUniversal and is called whenever
 * the controller sends data about it's current state. Do not call this
 * function directly
 *
 * This function resets the buttonState to 0. It then iterates over each button
 * shifting a 1 onto buttonState if it is pressed otherwise it leaves it at
 * zero. The end result is that the current state of each button is represented
 * as a single bit in buttonState. This will allow us to check the value of any
 * button by ANDing buttonState with a bit mask later on.
 *
 * @param hid
 * @param is_rpt_id
 * @param len Length of the buffer
 * @param buf The buffer
 */
void HIDController::ParseHIDData(USBHID *hid, bool is_rpt_id, uint8_t len, uint8_t *buf) {
  uint8_t value = 0;
  buttonState = 0;

  // For each button shift left then append the button state
  // UP is the left most bit, BUTTON_10 is right most
  for(uint8_t i = 0; i < MAX_HID_BUTTONS; i++) {
    buttonState <<= 1;  // Shift to the next bit
    if (buttons[i].mask == 0) continue; // Skip this bit as there is no button associated with it

    value = buf[buttons[i].index] & buttons[i].mask;  // Get the bits we care about
    if(value == buttons[i].value) {
      buttonState |= 1;  // Set the final bit
    }
  }

  // Update Click State and LastButtonState
  if(buttonState != lastButtonState) {
    clickState = buttonState & ~lastButtonState;
    lastButtonState = buttonState;
  }
}

/**
 * Unsets all buttons on the controller
 *
 * Sets all button masks to zero.  This signals to the system that the buttons
 * are unset and should not be used.
 */
void HIDController::ResetController() {
  for(uint8_t i = 0; i < MAX_HID_BUTTONS; i++) {
    buttons[i].mask = 0;
  }
}

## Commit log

2020-06-29 Create pcb
2020-08-03 Add files via upload
    Fixed X and O button for PS3
    [RFUSB_to_DB15.ino]
2020-08-09 Add files via upload
    Retrobit Sega Saturn wireless 8bit attempt to support
2020-08-10 Structural change and PCB
    Directory change and new board design.
    [RFUSBtoDB15Adapter.brd, RFUSBtoDB15Adapter.sch]
2020-08-10 Create RFUSBtoDB15Adapter.png
    PCB Layout
2020-08-11 Create USB2DB15-Adapter-schematic.pdf.pdf
    Schematic in PDF
2020-08-11 New PCB
    PCB updated
    [RFUSBtoDB15Adapter.brd, RFUSBtoDB15Adapter.sch]
2020-08-11 Update RFUSBtoDB15Adapter.brd
    Changes on PCB
    [RFUSBtoDB15Adapter.brd]
2020-08-12 Add support for USB connected LED
2020-08-13 Updates
    Schematic, PCB and code updates.
    [RFUSBtoDB15Adapter.brd, RFUSBtoDB15Adapter.sch]
2020-08-13 Update RFUSB_to_DB15.ino
    Brook Universal PCB support on PS4 mode
2020-08-13 Schematic PDF
    Fix on extension
2020-08-13 PCB
    Some changes
    [RFUSBtoDB15Adapter.brd, RFUSBtoDB15Adapter.sch]
2020-08-17 PCB
    PCB design updated
    [RFUSBtoDB15Adapter.brd, RFUSBtoDB15Adapter.sch]
2020-08-17 Update README.md
    Removed some unnecessary jumpers and PCB revised.
2020-08-23 Fix Device Button defines
    Fixes a skipped number in the button enum in device description. Prevented looping
2020-08-23 Add Hid Controller and Drivers
2020-08-23 Change UPCB VID and PID
2020-08-23 Added Function Comments to Drivers.cpp
2020-08-23 Clean up
    Removed Dead code from RFUSB_to_DB15
    Fixed some bugs
    [RFUSB_to_DB15.ino, drivers.cpp]
2020-08-24 Fixed DPad Down Left for HID
    [drivers.cpp]
2020-08-25 Clean up some missing line breaks
    [USB2DB15.cpp]
2020-08-27 PCB update
    Small changes
    [RFUSBtoDB15Adapter.brd, RFUSBtoDB15Adapter.sch]
2020-08-30 Add button clicked to HID Controller
2020-08-30 Fix Click Support For HIDController
    Add some fancy MASK manipulation to reduce some giant switch statements. Probably slower but easier to read
    [HIDController.cpp]
2020-09-02 Add VID and PID accessors to controllers
2020-09-02 Add Support for Per Device Profiles to USB2DB15
2020-09-12 Added LED & Reset
    [RFUSB_to_DB15.ino, USB2DB15.cpp]
2020-09-12 Change LED from a class to namespace
    Encapsulate all functions and code for LED control into a cpp file
2020-09-12 Updated Reset EEPROM Logic
    Removed unnesscary temp variable buttonValue
    Removed resetEEPROM and instead let the EepromManager handle the reset.
    [RFUSB_to_DB15.ino]
2020-09-12 Moved FactoryReset into USB2DB15
    Reset pid and vid values to inital state
    [RFUSB_to_DB15.ino, USB2DB15.cpp]
2020-09-12 Increase Button Threshold to 500
2020-09-12 WOL improvements to reset
    Added a Guard Lock to the reset function so it can only happen once per button press
    Increased Reset Threshold to 800
    Made LED blink 5 times
    Prints out "Resetting" while reseting
    Sets inital profile block to 0
    [EepromManager.cpp, RFUSB_to_DB15.ino]
2020-09-12 Adds a paramter to the LED::Blink() function to stipulate number of blinks and speed of blinks
    Removes:
    #define BLINK_HALF_LENGTH
    Adds a second parameter to:
    LED::Blink();
    To stipulate the speed of blinking.
2020-09-12 PCB Update
    LED status and MEMORY RESET now supported
    [RFUSBtoDB15Adapter.brd, RFUSBtoDB15Adapter.sch]
2020-09-12 Changed Magic numbers in LED to constants
2020-09-12 Update LED.cpp Comment
2020-09-16 Update
    Donation and schematic PDF
2020-09-16 Added Generic SNES pad
    Added Generic SNES pad
    Refactored Retrobit Saturn Wireless
2020-09-20 Update CHANGELOG.md
    Added info about M30 and 8BitDo wireless receivers
2020-09-20 Fixes START & SELECT being reversed
    Small fix for the Honcam joystick to rectify START & SELECT buttons being reversed.
    [drivers.cpp]
2020-10-05 Update PS3Controller.cpp
    Removed unnecessary LED stuff from PS3Controller::Connected() (sorry was something I was experimenting with and forgot to remove)
2020-10-09 Xbox Mapping and Analog
    Xbox 360 and Xbox One mapping issue fixed.
    Xbox One analog support added.
    PS3 analog support refined and bug fixed.
    Added serial output control.
    [EepromManager.cpp, HIDController.cpp, RFUSB_to_DB15.ino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]
2020-10-09 PCB Update
    [RFUSBtoDB15Adapter.brd, RFUSBtoDB15Adapter.csv, RFUSBtoDB15Adapter.sch]
2020-10-09 Small fix
    [RFUSBtoDB15Adapter.brd]
2020-10-14 Add a Null button for unbound keys
2020-10-14 Clear Unbound Profile buttons on early exit
2020-11-14 Revert "Merge pull request #49 from Raphfriend/Frank-fjs-patch-2"
    This reverts commit 7b12d3794918d97649cff50f625bace1fb1e8581, reversing
    changes made to aff03f1f39435062884922ed897bb8d5cb139e61.
    [RFUSB_to_DB15.ino]
2020-11-14 Revert "Revert "Merge pull request #49 from Raphfriend/Frank-fjs-patch-2""
    This reverts commit 92c274d6be7aaaae423d808fde2ac72dc8ca5392.
    [RFUSB_to_DB15.ino]
2020-11-19 Update drivers.cpp
    Comments fixed.
    [drivers.cpp]
2020-11-20 Update drivers.h
    Added notes for Arduino Leonardo VID and PID
2020-12-09 Update COMPATIBILITY.md
    - NES & SNES Bluetooth receviers tested compatible with the following controllers:
    - 8BitDo Arcade Stick (November 2020 version) on Switch mode and Firmware 1.03
2021-01-19 Update drivers.h
    Fixed the driver alphabet order.
2021-01-19 Update drivers.h
    - Fixed alphabet order for IDs
    - Added Razer Panthera EVO ID
2021-02-27 Update drivers.cpp
    Clean up code a bit and fix a comment
    [drivers.cpp]
2021-02-27 Update drivers.cpp
    Remove unneeded code
2021-03-10 Brook FB
    Add support for Brook FIGHTING BOARD
2021-03-14 Brook FIGHTING BOARD PS3/PS4
2021-06-20 Add section 4.2 for Arduino Mini Pro
2021-09-09 Update drivers.cpp
    Clean up Code Formatting
    Updated MADCATZ to not use 0xXF for buttons as that would conflict with the DPAD
2021-10-28 Zero delay PCB supported
2022-01-13 New PCB and Schematics
    PCB/Schematics REV 1.2
    [RFUSBtoDB15Adapter.brd, RFUSBtoDB15Adapter.sch]
2022-01-13 Update CHANGELOG.md
    New PCB and Schematics for Version 1.2 added with some fixes.
2022-05-13 Updates
    Added
    - FUSION Wired FightPad Gaming Controller for PlayStation 4
    Update Readme
2022-05-14 Pico Fighting Board GP2040
    - Support for new pads
    - Documentation updated
2022-05-26 Update drivers.cpp
    Added Logitech F310
2022-12-23 New controllers and some fixes
    [drivers.cpp]
2022-12-23 Fix Indentation on 8bitdo Case Statement
    [drivers.cpp]
2023-06-18 Gerber PCB V1.2 uploaded
    - V1.2 Gerber
    - BOM V1.2
    [RFUSBtoDB15Adapter.csv, USB2DB15_V1_2_BOM.csv]

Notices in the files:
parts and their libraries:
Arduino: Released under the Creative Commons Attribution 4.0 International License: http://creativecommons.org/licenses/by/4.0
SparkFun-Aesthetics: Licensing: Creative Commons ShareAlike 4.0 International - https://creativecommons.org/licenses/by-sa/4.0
